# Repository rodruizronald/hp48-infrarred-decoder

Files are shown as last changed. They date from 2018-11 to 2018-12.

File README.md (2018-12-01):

# HP-48GX-Infrarred-Signal-Decoder

The HP 48 is a series of graphing calculators capable of communicate with a wireless printer via infrared signals. The protocol used by these calculators, called "Rey Eye", operates in a frequency of 33 kHz. This project aims to replicate a program that runs in an HP 48GX to read an electronic people counter. Reading the counters with a calculator is not practical, and therefore a specific device should be built for this task. To construct such device the project was divided into three parts.

First, the signals emitted by the calculator's program were decoded with an IR sensor conneceted to an oscilloscope and then replicated with an Atmega328p. After decoding the infrared signals, the results were examined to understand better the protocol. This examination provided the required information to code a program capable of reading the infrared signals. Finally, to implement the emitter and receiver code in a functional device, a PCB board was designed.

Although this project focuses on a specific program to read electronic people counter, it can be used as a starting point for others since the communication protocol is the same for all applications.

## Red Eye Protocol

The Red Eye Frame is composed of 15 bits:

* 1.5 start bits.   
* 4 error bits.
* 8 data bits.
* 1.5 stop bits.

<p align="center">
  
</p>

Generally, the length of each bit within the frame is 854.5 us, but this value could vary depend on the IR sensor implemented. It is advisable to test with an oscilloscope the output of the sesor before making any assumptions. The logic level of one bit is defined by the position of a high state within the pulse. The high state takes 244 us, time in which the IR Led is switching on and off every 15.15 us (one cycle 30.3 us).

<p align="center">
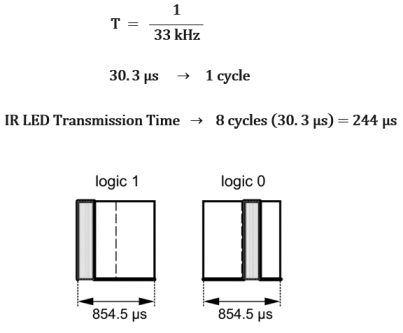
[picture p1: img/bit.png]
  
</p>

## Prototype

The PCB prototype contains both an IR sensor and LED to implement a bidirectional communication with the electronic counter. Additionally, a wireless LAN module was added to request and get the data remotely. The implementation of this module will be discussed in another repository to maintain this one consistent.

<p align="center">
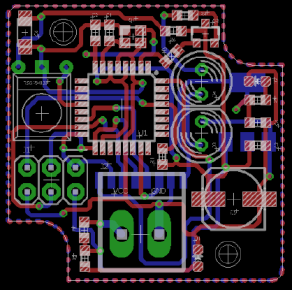
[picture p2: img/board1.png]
  
</p>

## Software

* Atmel Studio 6.0 - Integrated Development Platform for developing and debugging AVR microcontrollers.
* Eagle PCB Design - PCB layout and schematic design software.

## License

This project is licensed under the MIT License - see the [LICENSE.md](LICENSE.md) file for details.

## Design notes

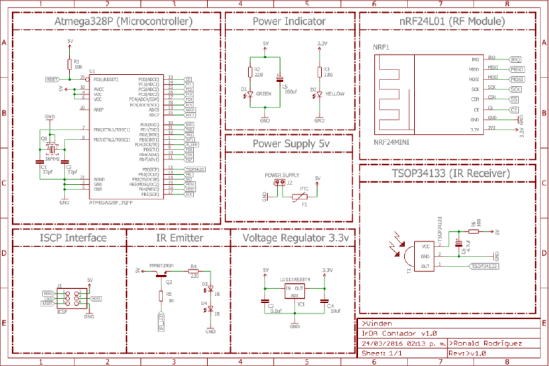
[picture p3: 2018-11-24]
img/schematic.png

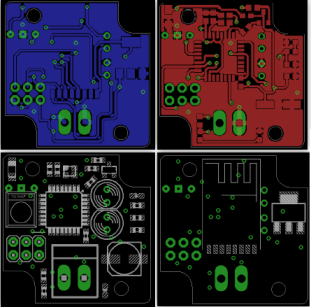
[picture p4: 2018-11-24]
img/board2.png

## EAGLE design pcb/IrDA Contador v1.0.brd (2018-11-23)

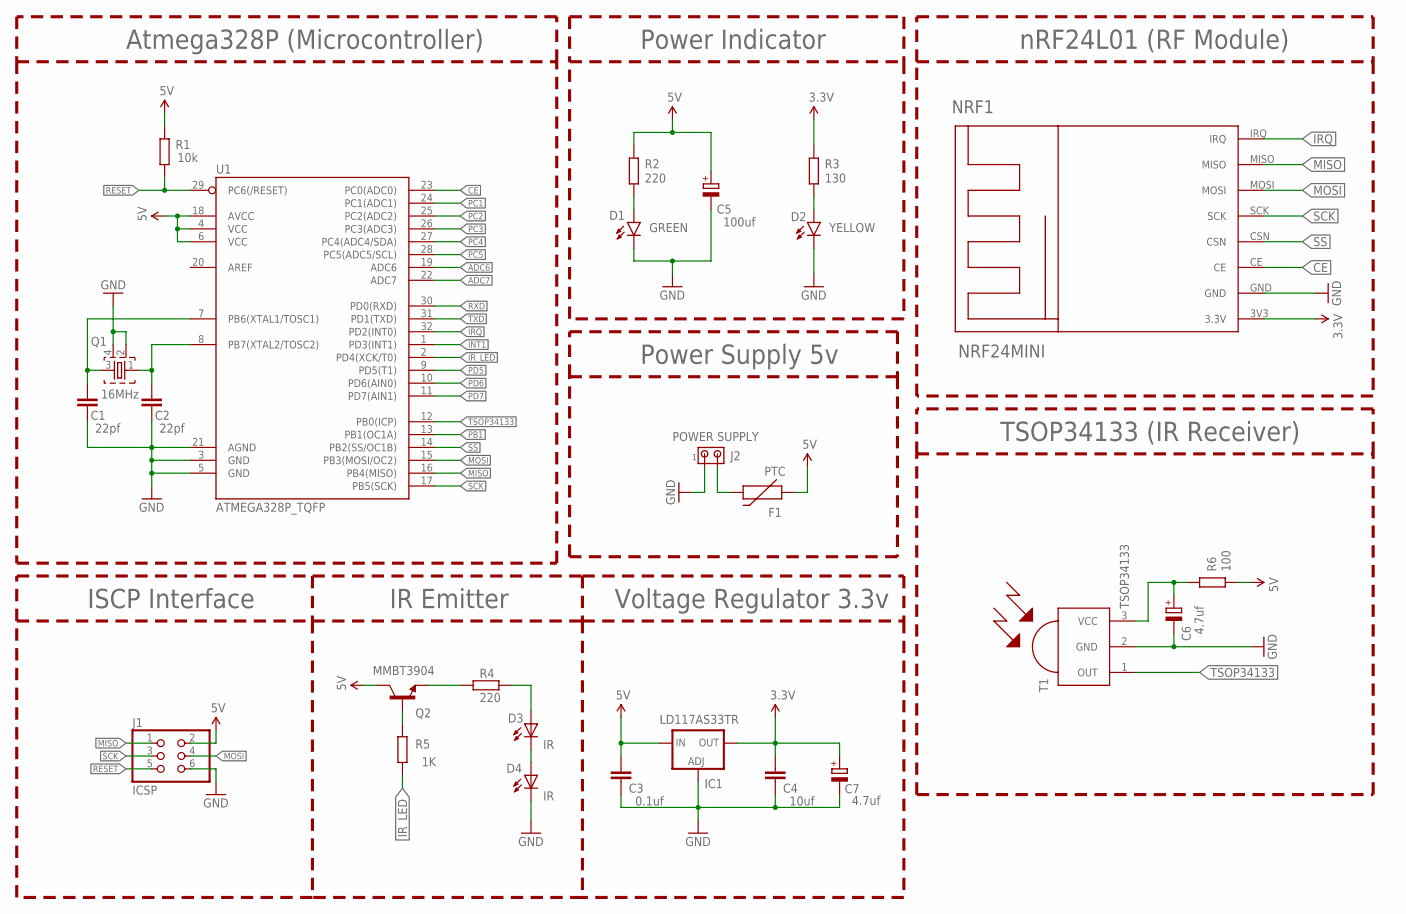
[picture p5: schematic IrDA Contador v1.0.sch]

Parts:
C1, C2: 22pf; C0603
C3: 0.1uf; C0603
C4: 10uf; C0603
C5: 100uf; 153CLV-0605
C6, C7: 4.7uf; SMC_A
D1: GREEN; LED-0603
D2: YELLOW; LED-0603
D3, D4: IR; LED5MM
F1: PTC; 0603
IC1: LD117AS33TR; SOT223
J1: ICSP; 2X03
J2: POWER SUPPLY; 1X2MTA
NRF1: NRF24MINI
Q1: 16MHz; FA-20H
Q2: MMBT3904; SOT23-3
R1: 10k; R0603
R2, R4: 220; R0603
R3: 130; R0603
R5: 1K; R0603
R6: 100; R0603
T1: TSOP34133
U1: ATMEGA328P_TQFP; TQFP32-08

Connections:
3.3V: C4.2, C7.+, IC1.4 (OUT), NRF1.3V3 (3.3V), R3.2
5V: C3.2, C5.+, F1.1, IC1.3 (IN), J1.2, Q2.3 (C), R1.2, R2.2, R6.1, U1.4 (VCC), U1.6 (VCC), U1.18 (AVCC)
ADC6: U1.19 (ADC6)
ADC7: U1.22 (ADC7)
CE: NRF1.CE, U1.23 (PC0(ADC0))
GND: C1.1, C2.1, C3.1, C4.1, C5.-, C6.-, C7.-, D1.C, D2.C, D4.K (C), IC1.1 (ADJ), J1.6, J2.1, NRF1.GND, Q1.2, Q1.4, T1.2 (GND), U1.3 (GND), U1.5 (GND), U1.21 (AGND)
INT1: U1.1 (PD3(INT1))
IRQ: NRF1.IRQ, U1.32 (PD2(INT0))
IR_LED: R5.2, U1.2 (PD4(XCK/T0))
MISO: J1.1, NRF1.MISO, U1.16 (PB4(MISO))
MOSI: J1.4, NRF1.MOSI, U1.15 (PB3(MOSI/OC2))
unnamed: D2.A, R3.1
unnamed: C1.2, Q1.3, U1.7 (PB6(XTAL1/TOSC1))
unnamed: C2.2, Q1.1, U1.8 (PB7(XTAL2/TOSC2))
unnamed: D1.A, R2.1
unnamed: Q2.2 (E), R4.2
unnamed: D3.A, R4.1
unnamed: D3.K (C), D4.A
unnamed: C6.+, R6.2, T1.3 (VCC)
unnamed: F1.2, J2.2
unnamed: Q2.1 (B), R5.1
PB1: U1.13 (PB1(OC1A))
PC1: U1.24 (PC1(ADC1))
PC2: U1.25 (PC2(ADC2))
PC3: U1.26 (PC3(ADC3))
PC4: U1.27 (PC4(ADC4/SDA))
PC5: U1.28 (PC5(ADC5/SCL))
PD5: U1.9 (PD5(T1))
PD6: U1.10 (PD6(AIN0))
PD7: U1.11 (PD7(AIN1))
RESET: J1.5, R1.1, U1.29 (PC6(/RESET))
RXD: U1.30 (PD0(RXD))
SCK: J1.3, NRF1.SCK, U1.17 (PB5(SCK))
SS: NRF1.CSN, U1.14 (PB2(SS/OC1B))
TSOP34133: T1.1 (OUT), U1.12 (PB0(ICP))
TXD: U1.31 (PD1(TXD))

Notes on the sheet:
nRF24L01 (RF Module)
Atmega328P (Microcontroller)
TSOP34133 (IR Receiver)
ISCP Interface
Power Supply 5v
Voltage Regulator 3.3v
Power Indicator
IR Emitter

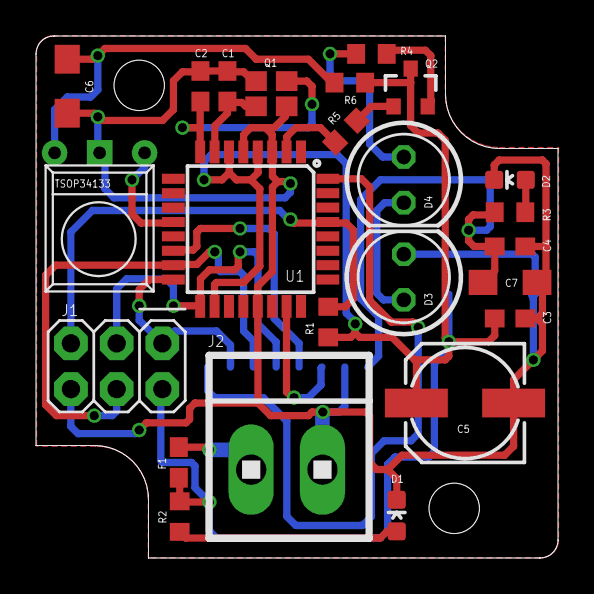
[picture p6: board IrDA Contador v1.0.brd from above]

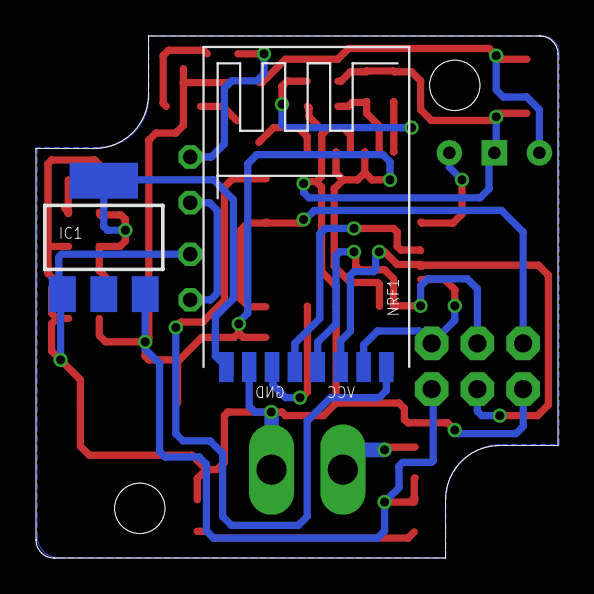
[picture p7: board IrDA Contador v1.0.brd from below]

Board: 2 copper layers, 29.0 x 29.0 mm, 26 parts (2 on the bottom side), 22 nets.

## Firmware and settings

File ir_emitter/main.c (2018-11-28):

//*****************************************************************************
//
//  Test of the Red Eye protocol used by HP 48GX calculators (Emitter).
//  File:     main.c
//  Author:   Ronald Rodriguez Ruiz.
//  Date:     September 30, 2016.
//  ---------------------------------------------------------------------------
//  Specifications:
//  The following code was tested in an atmega328p to send predefined commands
//  to another microcontroller running the ir_receiver code. The IR LED should
//  be connected to PD4 for infrared signal transmission.
//
//*****************************************************************************

#include <avr/io.h>
#include <util/delay.h>
#include "ir_emitter.h"

void main()
{
  //
  //  Initialize the IR emitter
  //
  IR_Emitter_init();

  //
  //  Send the clean memory command once
  //
  IR_send_request(CLEAN_MEMORY);
  while(1)
  {
    //
    //  Request the count every second
    //
    IR_send_request(GET_COUNTER);
    _delay_ms(1000);
  }
}

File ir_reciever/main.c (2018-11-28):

//*****************************************************************************
//
//  Test of the Red Eye protocol used by HP 48GX calculators.
//  File:     main.c
//  Author:   Ronald Rodriguez Ruiz.
//  Date:     September 30, 2016.
//  ---------------------------------------------------------------------------
//  Specifications:
//  The following code was tested in an atmega328p to read 12 data bytes sent
//  by a HP 48GX calculator. To read the frame sent by the calculatator a TSOP
//  1733 was used as IR sensor. The sensor must be connected to PD2, otherwise
//  the Inpute Capture mode will not work.
//
//*****************************************************************************

#include <stdint.h>
#include <avr/io.h>
#include <avr/interrupt.h>
#include "ir_reciever.h"
#include "uart.h"

void main()
{
  uint8_t* data;

  //
  //  Initialize the IR reciver
  //
  IR_Reciever_init();

  //
  //  Enable global interrupts.
  //
  sei();

  while(1)
  {
    //
    //  Check if there is any data available
    //
    if(IR_is_data_available())
    {
      //
      //  Get the data from the IR reciever and print it out
      //
      data = IR_get_data();
      for (uint8_t i = 0; i < 12; i++)
      {
        UART_printf("Byte: %u\n", *data++);
      }
    }
  }
}

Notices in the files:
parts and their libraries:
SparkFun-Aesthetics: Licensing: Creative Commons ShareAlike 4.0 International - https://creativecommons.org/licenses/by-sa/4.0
